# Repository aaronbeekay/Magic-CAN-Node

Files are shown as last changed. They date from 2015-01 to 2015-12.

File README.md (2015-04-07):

Magic-CAN-Node
==============

Magic CAN Node is a multifunctional, Controller Area Network (CAN)-enabled sensor interface module. It has the ability to connect, measure, and transmit data from a wide variety of sensors.

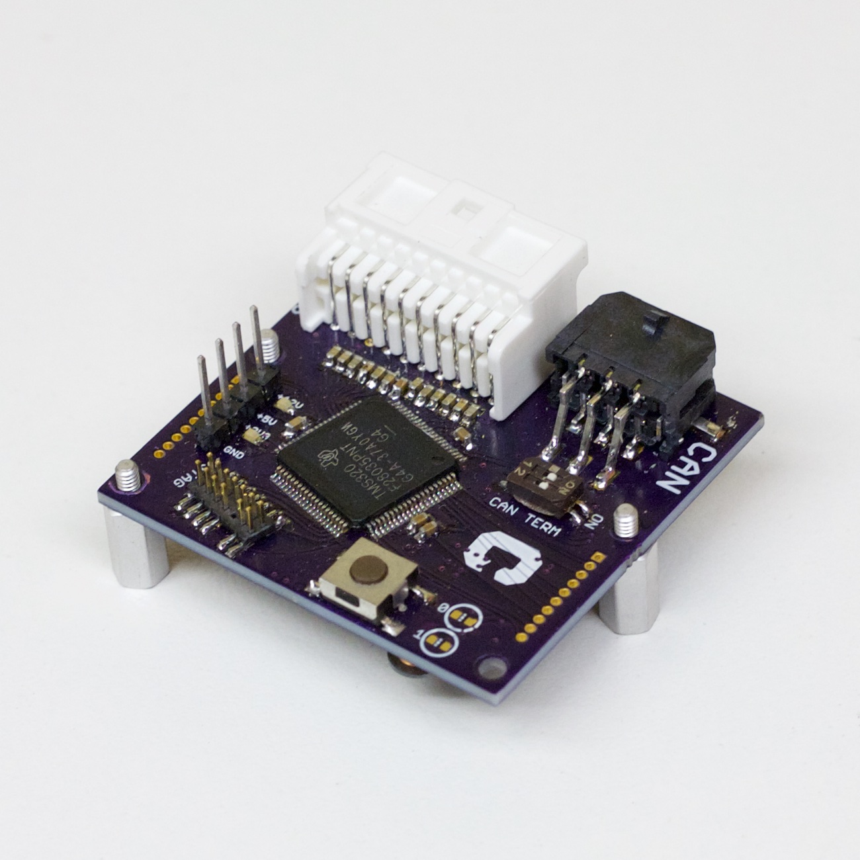
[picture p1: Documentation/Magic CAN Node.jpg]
Magic CAN Node


It's based on the Texas Instruments C2000 Piccolo, a 32-bit microcontroller with useful features. 

Some important features of the Magic CAN Node include:
* 12 analog inputs with buffering and anti-aliasing
* An onboard pushbutton and two general-purpose LEDs
* Access to SPI, I2C, and serial interfaces, as well as power and ADC pins, through standard "backpack" header
* Robust CAN interface, with onboard CAN termination
* Powered from +12V, with a wide 6-42V input range

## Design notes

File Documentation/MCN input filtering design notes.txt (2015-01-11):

Options for active filtering of analog inputs on MCN v2

1. Per-channel active filters
	- because of cost and board space concerns, anti-aliasing filter order is limited
	- seems practical to implement 2-order Butterworth (=24 op-amps, 6x TSSOP-16 packages)

2. External ADC
	- options:
		- TI ADS7953
			- 12-bit, 12- or 16-channel
			- has mux breakout for filtering
			- http://www.ti.com/lit/ds/symlink/ads7953-q1.pdf
		- TI ADS1158
			- 16-bit
			- 16-channel
			- http://www.ti.com/product/ads1158
			- SPI interface
		
3. External mux
	- two 12-channel muxes: still use the C2000 internal mux, but switch a "nice" signal conditioning filter inline into the channel of interest
	- options:
		- TI CD4067B
			- http://www.ti.com/product/cd4067b
			
FILTER DESIGN IDEAS
- cheater chip: http://www.ti.com/lit/ds/symlink/uaf42.pdf

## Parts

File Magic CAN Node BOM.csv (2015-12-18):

Qty | Description | Manufacturer | Mfg Name | Mfg part | Vendor | Vendor Part Num | Cost | Designator
12 | Capacitor, Ceramic, 33 nF, 50V, X7R, 10% | Passive | AVX | 06035C333KAT2A | NW | 66H6168 | 0.018 | C7, C8, C9, C10, C11, C12, C13, C15, C19, C20, C21, C28
1 | DIP switch, 0.05"""" pitch, 2pos, 50V | Switches | CTS Electrocomponents | 218-2LPST | DK | CT2182LPST-ND | 1.06 | SW3
2 | Header, female pin, 10x1pos, 1.27 mm pitch, select gold plated, through hole | Connectors | Multicomp | 2206SA-10-46 | NW | 11N6311 | 0.835 | X1, X2
1 | Micro-Fit header, 6pos, RA, SMD, with solder tabs | Connectors | Molex | 43045-0609 | DK | WM1827CT-ND | 3.2 | X3
1 | Micro-Clasp header, 20pos, 2 rows, RA, through-hole | Connectors | Molex | 55959-2030 | NW | 09J7572 | 1.13 | X5
1 | Schottky rectifier, 30V, 1A, SMA | Passives | Diodes Inc | B130-13-F | DK | B130-FDICT-ND | 0.43 | D1
4 | Inductor, Chip, 60ohm, 1.5A, 0603 | Passives | Taiyo Yuden | BKP1608HS600-T | DK | 587-1928-1-ND | 0.047 | L2, L3, L4, L5
4 | Capacitor, Ceramic, .1uF 25V 10% 0603 X7R | Passives | TDK | C1608X7R1E104K080AA | DK | 445-1316-1-ND | 0.011 | C22, C23, C24, C32
3 | Resistor, 169 ohm 125 mW, 1%, 100ppm, Thick Film 0805 | Passives | Vishay Dale | CRCW0805169RFKEA | NW | 52K9913 | 0.005 | R15, R36, R37
2 | Schottky diode, 30V, 800 mA, USC/SOT-323 | Passives | Toshiba | CUS08F30 | DK | CUS08F30H3FCT-ND | 0.34 | D8, D9
1 | Choke, common mode, 100 uH, 500 mA, 25% | Passives | Bourns Inc | DR331-104AE | NW | 29T3649 | 0.32 | L7
12 | Resistor, 100 kohm, 100mW, 1%, Thick Film, 0402 | Passives | Panasonic | ERJ-2RKF1003X | NW | 64R5249 | 0.014 | R20, R21, R22, R23, R24, R25, R26, R27, R28, R29, R30, R31
16 | Resistor, 1 kohm 100 mW, 1%, Thick Film, 0603 | Passives | Panasonic | ERJ-3EKF1001V | NW | 64R5308 | 0.012 | R1, R2, R3, R4, R5, R6, R7, R8, R9, R10, R11, R12, R13, R18, R32, R33
1 | Resistor, 5.6 kohm, 100 mW, 1%, 0603 | Passives | Panasonic | ERJ-3EKF5601V | NW | 64R5354 | 0.096 | R16
4 | Resistor, 60.4 ohm, 100 mW, 1%, 0603 | Passives | Panasonic | ERJ-3EKF60R4V | NW | 65T8495 | 0.096 | R17, R19, R34, R35
1 | Resistor, 1.5k ohm 125 mW, 5%, Thick Film, 200ppm, 0805 | Passives | Panasonic | ERJ-6GEYJ152V | NW | 65T8789 | 0.003 | R14
1 | Tactile switch, SPST-NO, 0.05A, 12V | Switches | TE Connectivity | FSM1LPATR | DK | 450-1760-1-ND | 0.33 | SW2
1 | 0.05"""" male pin header, 2 rows, 14 positions (TI JTAG) - surface mount, vertical | Connectors | Samtec | FTS-107-01-F-DV | NW | 56P3763 | 0.9 | X6
7 | Capacitor, Ceramic, 2.2UF, 10%, 25V, 0603, X5R | Passives | Murata | GRM188R61E225KA12D | NW | 13T1193 | 0.107 | C1, C2, C3, C4, C5, C6, C17
1 | Capacitor, Ceramic, 4.7 nF, 50V, X7R, 10%, 0603 | Passives | Murata | GRM188R71H472KA01D | NW | 38K1673 | 0.006 | C18
2 | Capacitor, Ceramic, 22 uF, 6.3V, X5R, 20%, 0805 | 22 uF | Murata | GRM21BR60J226ME39L | NW | 24R6338 | 0.091 | C30, C31
1 | Capacitor, Ceramic, 10UF, 35V, X5R, 10%, 1206 | Passives | Murata | GRM31CR6YA106KA12L | NW | 72R4211 | 0.355 | C16
1 | Capacitor, Ceramic, 1 uF, 50V, X7R, 10%, 1210 | Passives | Murata | GRM32RR71H105KA01L | NW | 97K0677 | 0.248 | C29
2 | LED, Green, 0603, 10mcd | LEDs | Osram | LGQ971 | NW | 05M0493 | 0.054 | LED2, LED3
1 | LED, Green, 0603, 10mcd | LEDs | Osram | LGQ971 | NW | 05M0493 | 0.054 | LED0
1 | IC, DC-DC Conv, Buck, 42 Vin, 1.25 MHz, SOT23-6 | ICs | Texas Instruments | LMR14206XMKE/NOPB | NW | 76T5004 | 2.72 | IC2
1 | IC, LDO VOLT REG, 3.3V, 0.5A, SOT-223-5 | ICs | Texas Instruments | LP38693MP-3.3/NOPB | NW | 41K7496 | 1.53 | IC3
1 | Female pin header, 2x3 pos, 2mm pitch, selective gold plated | Connectors | Harwin | M22-7140342 | DK | 952-1357-5-ND | 1.15 | X4
1 | Capacitor, Ceramic, 4.7 uF 25V, 10%, X5R, 0805 | Passives | Multicomp | MC0805X475K250CT | NW | 06R4181 | 0.037 | C14
3 | ZENER DIODE, 200mW, 3.3V, SOD-323 | Passives | ON Semiconductor | MM3Z3V3ST1G | NW | 09R9503 | 0.15 | D5, D6, D7
2 | Resistor, Thick Film, 20 kohm, 100 mW, 1%, 0603 | Passives | Vishay Dale | RC0603FR-0720KL | NW | 68R0068 | 0.017 | R43, R44
1 | Resistor, 36 kohm, 1%, 100 mW, 0603 | Passives | Yageo | RC0603FR-0736KL | DK | 311-36.0KHRCT-ND | 0.0108 | R47
1 | Resistor, 10k ohm 100 mW, 5%, 100ppm, 0603 | Passives | Yageo | RC0603JR-1010KL | NW | 68R0215 | 0.008 | R46
1 | Inductor, 18 uH, 1.5 A, unshielded, 15%, 8012 | Passives | Bourns | SDR0604-180YL | DK | SDR0604-180YLCT-ND | 0.47 | L6
2 | TVS DIODE 30VWM 48.4VC SMB | Passives | Littelfuse | SMBJ30CA | DK | SMBJ30CALFCT-ND | 0.423 | D3, D4
1 | LED, Yellow, 0603, 14mcd | LEDs | Lumex | SML-LX0603YW-TR | NW | 75K1443 | 0.152 | LED1
1 | IC, CAN TX/RX, 1 MBps, 5.5V, 8-SOIC | ICs | Texas Instruments | SN65HVD1050D | NW | 70K4439 | 1.32 | IC8
1 | IC, Buffer, 2-bit, non-invert, open drain, SOT-23-6 | ICs | Texas Instruments | SN74LVC2G07DBVR | DK | 296-13494-1-ND | 0.59 | IC5
1 | Diode, Schottky, 40V, 500 mA, SOD-123 | Passives | STMICROELECTRONICS | STPS0560Z | NW | 89K1573 | 0.762 | D2
3 | IC, Quad Op-Amp, Single Supply Rail-Rail, 500 KHz, TSSOP-14 | ICs | Texas Instruments | TLV2764IPWR | NW | 76C8534 | 3.06 | IC4, IC6, IC7
1 | IC, MCU, C2000 piccolo, LQFP80 | ICs | Texas Instruments | TMS320F28035PNT | DK | 296-32764-ND | 12.38 | IC1

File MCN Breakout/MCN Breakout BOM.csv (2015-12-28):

Qty | Description | Category | Manufacturer | Mfg part | Vendor | Vendor Part | Cost | Part References
1 | Header, Male pin, .1", 1-row, 20 pos, breakable (Short Pins) | Connectors | FCI | 68000-236HLF | DK | 609-3465-ND | 1.44 | SV2, SV3
1 | Micro-Fit header, 6pos, RA, SMD, with solder tabs | Connectors | Molex | 43045-0609 | DK | WM1827CT-ND | 3.2 | X7
1 | MicroClasp plug, 20pos, dual row | Connectors | Molex | 51353-2000 | DK | WM3363-ND | 0.73 | X1
1 | 0.1" Male Header - 2 rows, 14 positions (TI JTAG) - Through Hole, Vertical | Connectors | FCI | 67996-114HLF | DK | 609-3491-ND | 0.75 | SV1
1 | BNC jack, 50 ohm, PCB mount, right-angle | Connectors | Molex | 73171-4230 | DK | WM5281-ND | 1.61 | X6
1 | DE-9 (DB-9) receptacle, 9 positions, PCB mount, right-angle | Connectors | TE Connectivity | 1734354-1 | DK | A35107-ND | 1.43 | X8
1 | Male pin header, 2x3pos, 2mm pitch, selective gold plated | Connectors | Harwin | M22-2520305 | DK | 952-1318-ND | 0.43 | X2
2 | Female pin header, 10 pos, 2mm pitch, selective gold plated | Connectors | Harwin | M22-7131042 | DK | 952-1354-5-ND | 1.49 | X10, X11
1 | Binding post, insulated, red, 6-32 stud size | Connectors | Cinch Connectivity | 111-0702-001 | DK | J10125-ND | 4.05 | X5
1 | Binding post, insulated, black, 6-32 stud size | Connectors | Cinch Connectivity | 111-0703-001 | DK | J10126-ND | 4.05 | X4

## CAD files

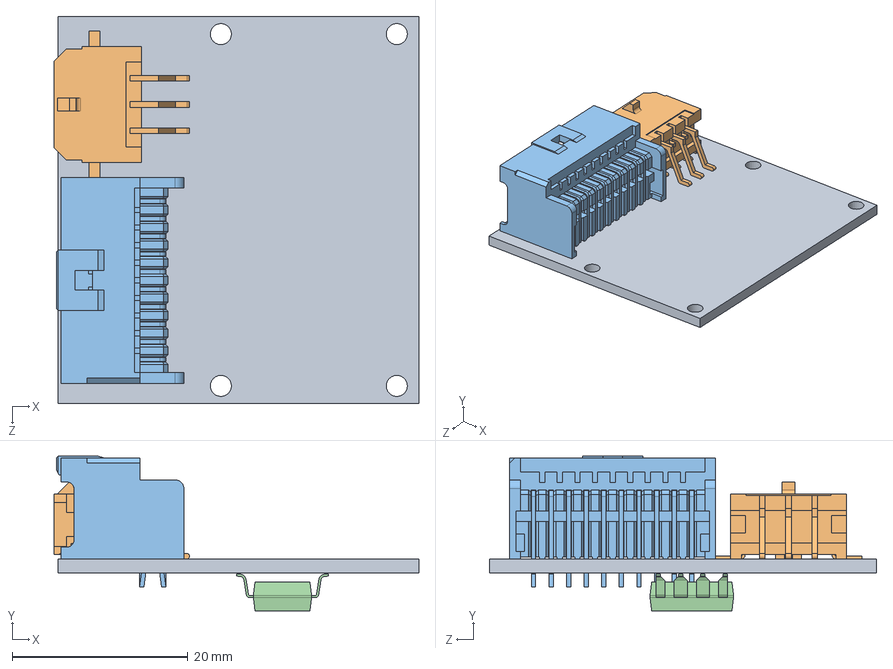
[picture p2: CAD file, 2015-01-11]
MCAD/Magic CAN Node.SLDASM
41.5 x 17.6 x 44.0 mm
Magic CAN Node PCB
Molex MicroFit 6pos RA header - solder tabs - 43045-0609
Micro-Clasp 20ckt dual-row header - 55959-2030
8-DUB__R-PDSO-8

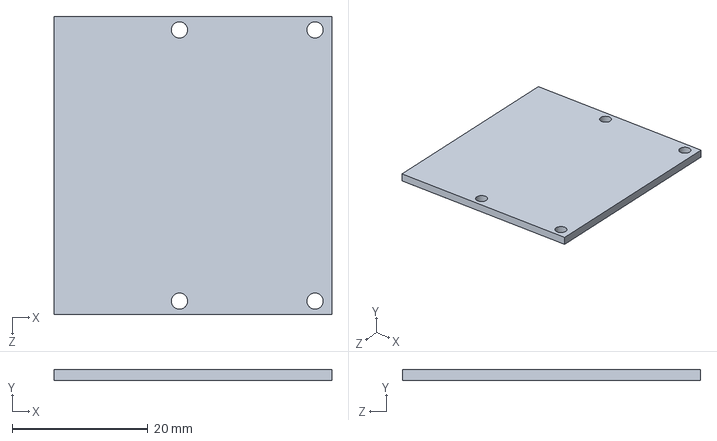
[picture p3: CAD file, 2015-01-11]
MCAD/Magic CAN Node PCB.SLDPRT
41.0 x 1.60 x 44.0 mm

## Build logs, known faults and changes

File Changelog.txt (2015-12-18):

Magic CAN Node - changelog

# v1.0.0 (r01)
(initial draft)

# v1.0.1 (r02) - 2014-02-10
- Fix incorrect drill size for X4.
- Add mating connectors and terminals as BOM entries in schematic (instead of manually adding later).
- Invert 12V switching to avoid glitch on processor startup
- Update TI component packages (IC5, IC6) to DBV package to match stocked components
- FIXME: Replace unsourceable ESD protection arrays IC7, IC2

VERSION NUMBERING UPDATE - November 2014
r02 is now v1.0.1.

# v.2.0 - 2014-12-04
- Redesign analog sensor input filter circuit to reflect new sensor measurement strategy:
	* Analog filter on each channel is an RC anti-aliasing filter with f_3dB = 5 kHz
	* Add option for differential-mode analog inputs (AINx to AIN-)
- Change 12V-3V3 power supply: use circuit from Battery Interface Module r02 (v.1.0.1) because TPS560200-based circuit from Magic CAN Node v.1.0.1 was unsourceable
- Remove ESD protection diode arrays
- Remove switched +12V output and associated circuit
- Change CAN connectors: remove AMPSEAL CAN connectors, replace with Micro-Fit 6pin
- Change JTAG header to 0.05" pitch
- Remove 'CAN_RESET' button
- Add '+3V3 OK' and '+12V OK' indicator LEDs

# v2.1 - 2015-03-23
- Replace CAN transceiver (ISO1050) with replacement (SN65HVD1050), for standardization
- Add 100k pulldowns to analog inputs.
- Tie VREFHI to +3V3 to enable ratiometric analog measurements.

# v2.2 - 2015-12-xx
- Add GPIO input filter circuit to general-purpose inputs.
- Add blind-mate input header, X4, to enable usage as daughtercard (no wire-to-board connections).
- Change CAN transceiver level-shifting diode, D5, from 3V to 3.3V to reduce unique part count.
- Fix LED resistor values and change components accordingly.

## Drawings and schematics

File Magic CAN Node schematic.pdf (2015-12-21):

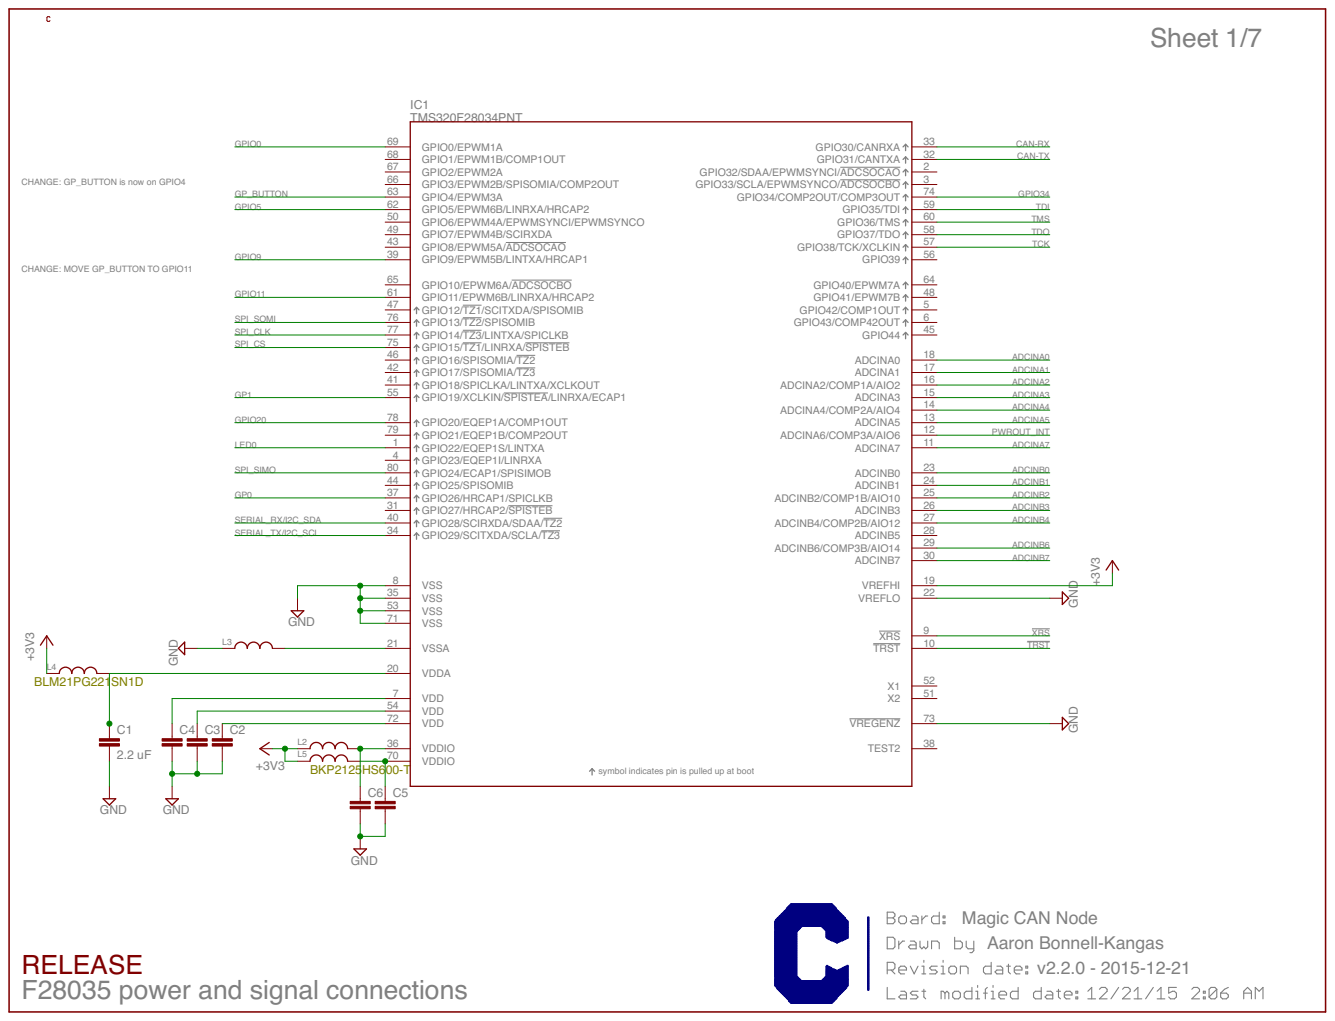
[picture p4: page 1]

CAN-RX CAN-TX

CHANGE: GP_BUTTON is now on GPIO4

35
53 | | 9 TRST XRS 10 TRST 52

symbol indicates pin is pulled up at boot

RELEASE
F28035 power and signal connections

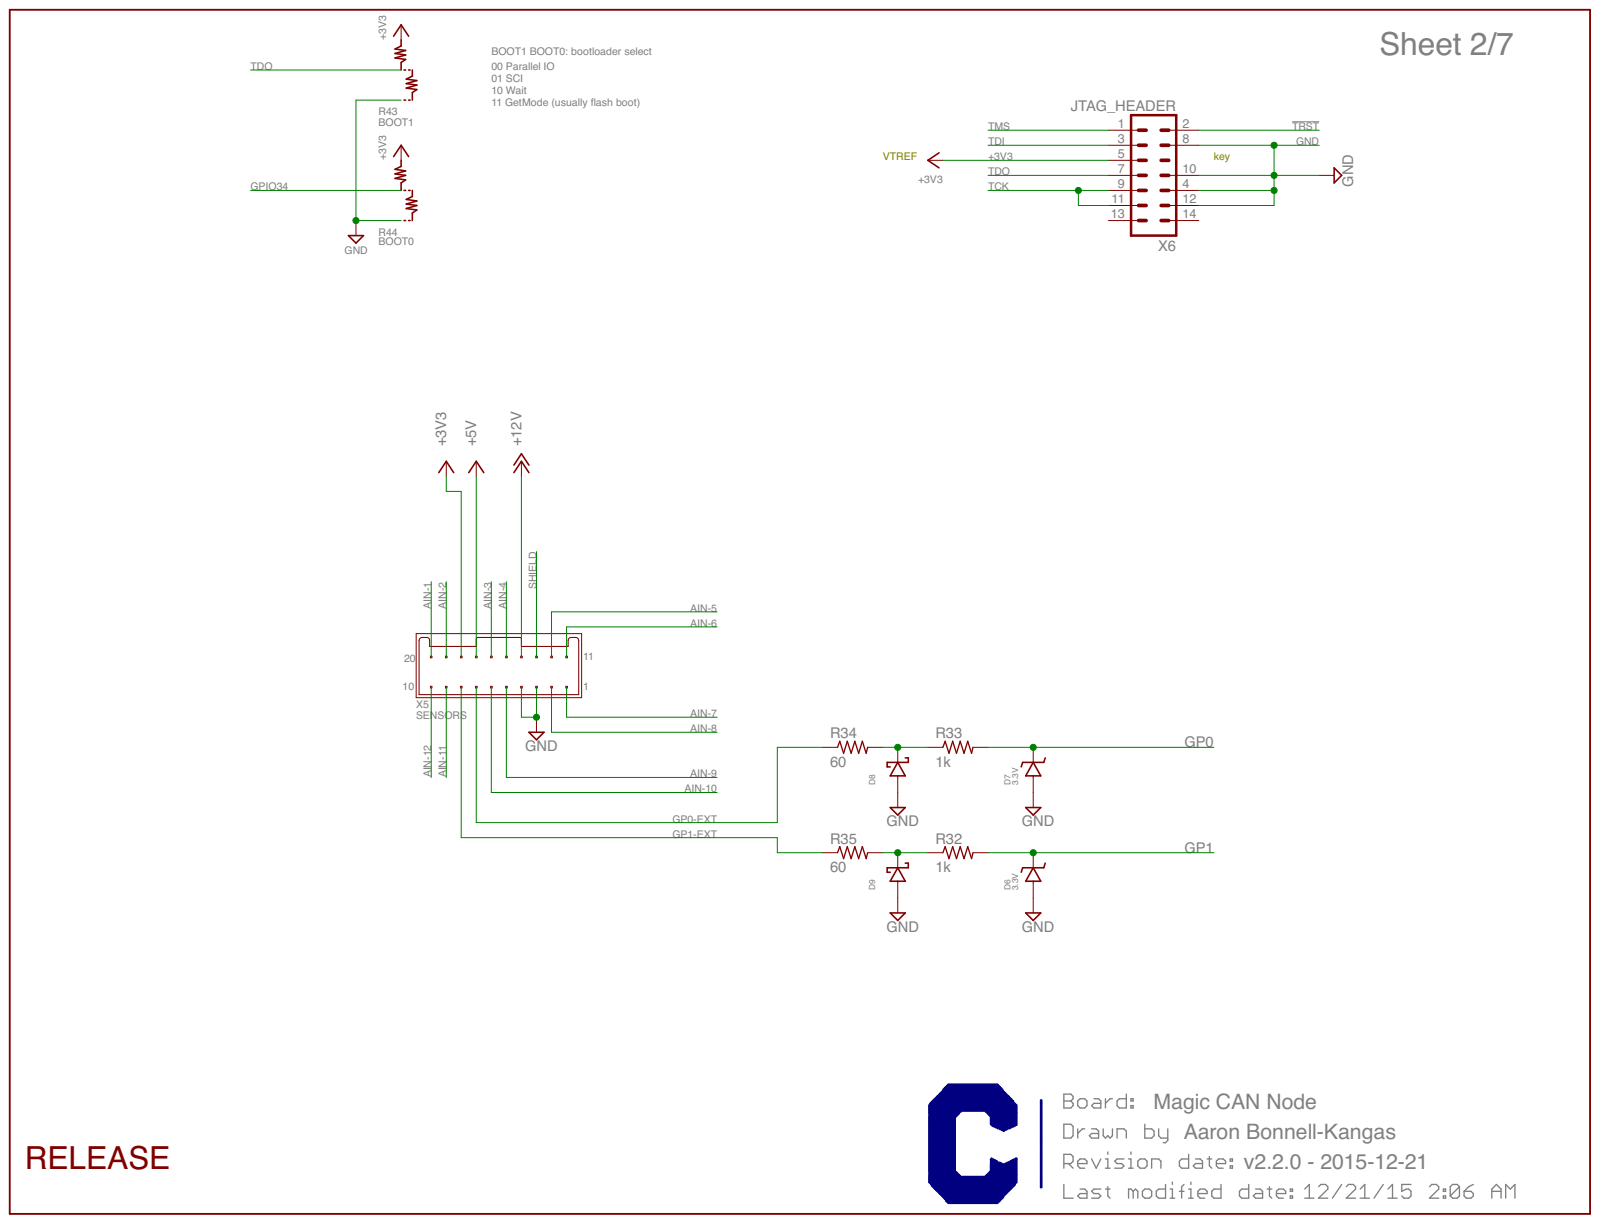
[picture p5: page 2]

BOOT1 BOOT0: bootloader select 00 Parallel IO

01 SCI 10 Wait 11 GetMode (usually flash boot)

AIN-1 AIN-2 AIN-3 AIN-4SHIELD

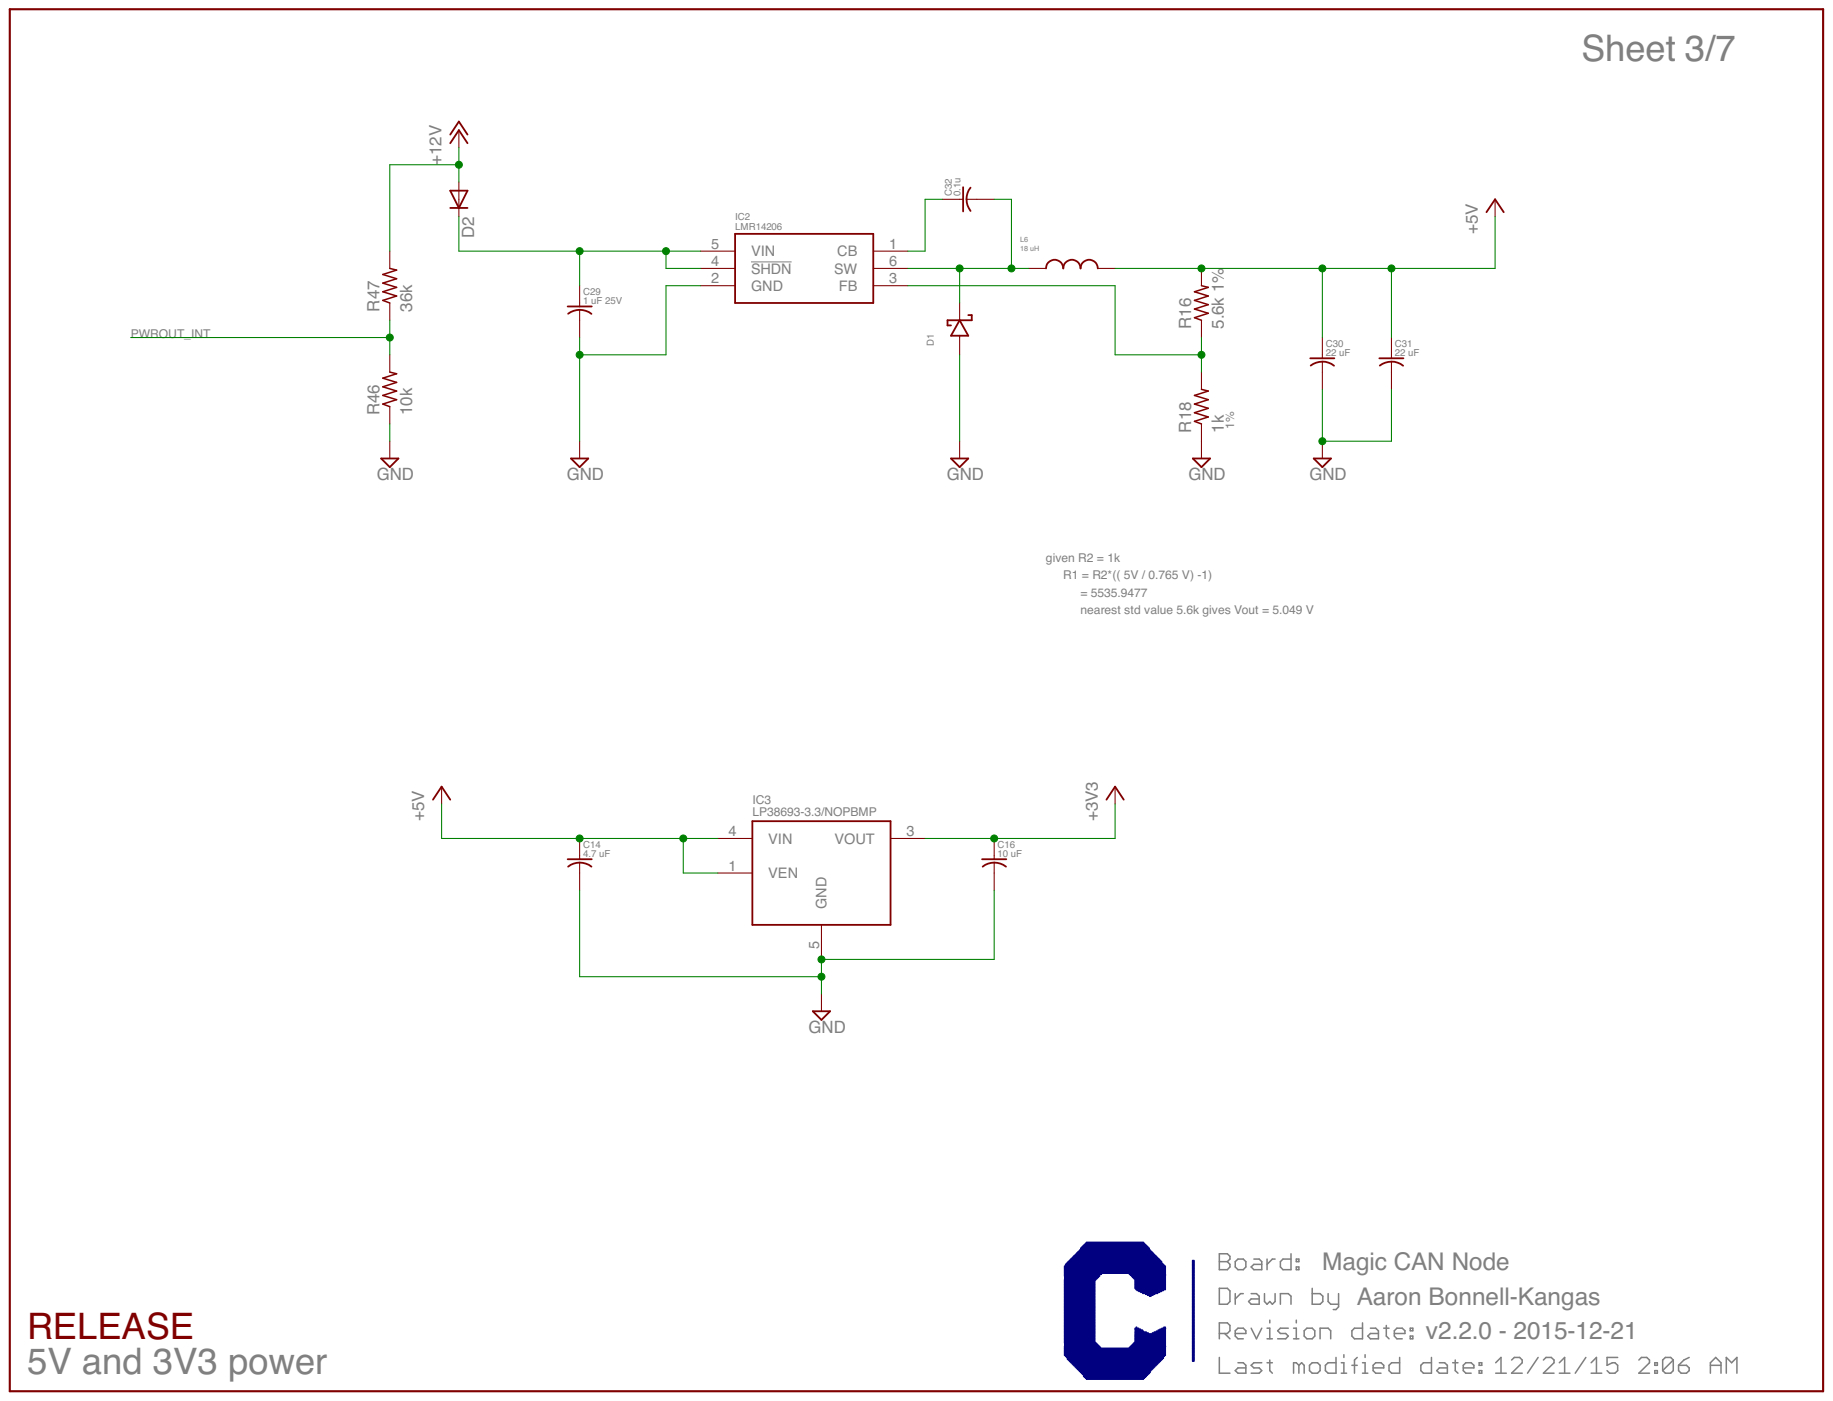
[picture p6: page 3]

nearest std value 5.6k gives Vout = 5.049 V

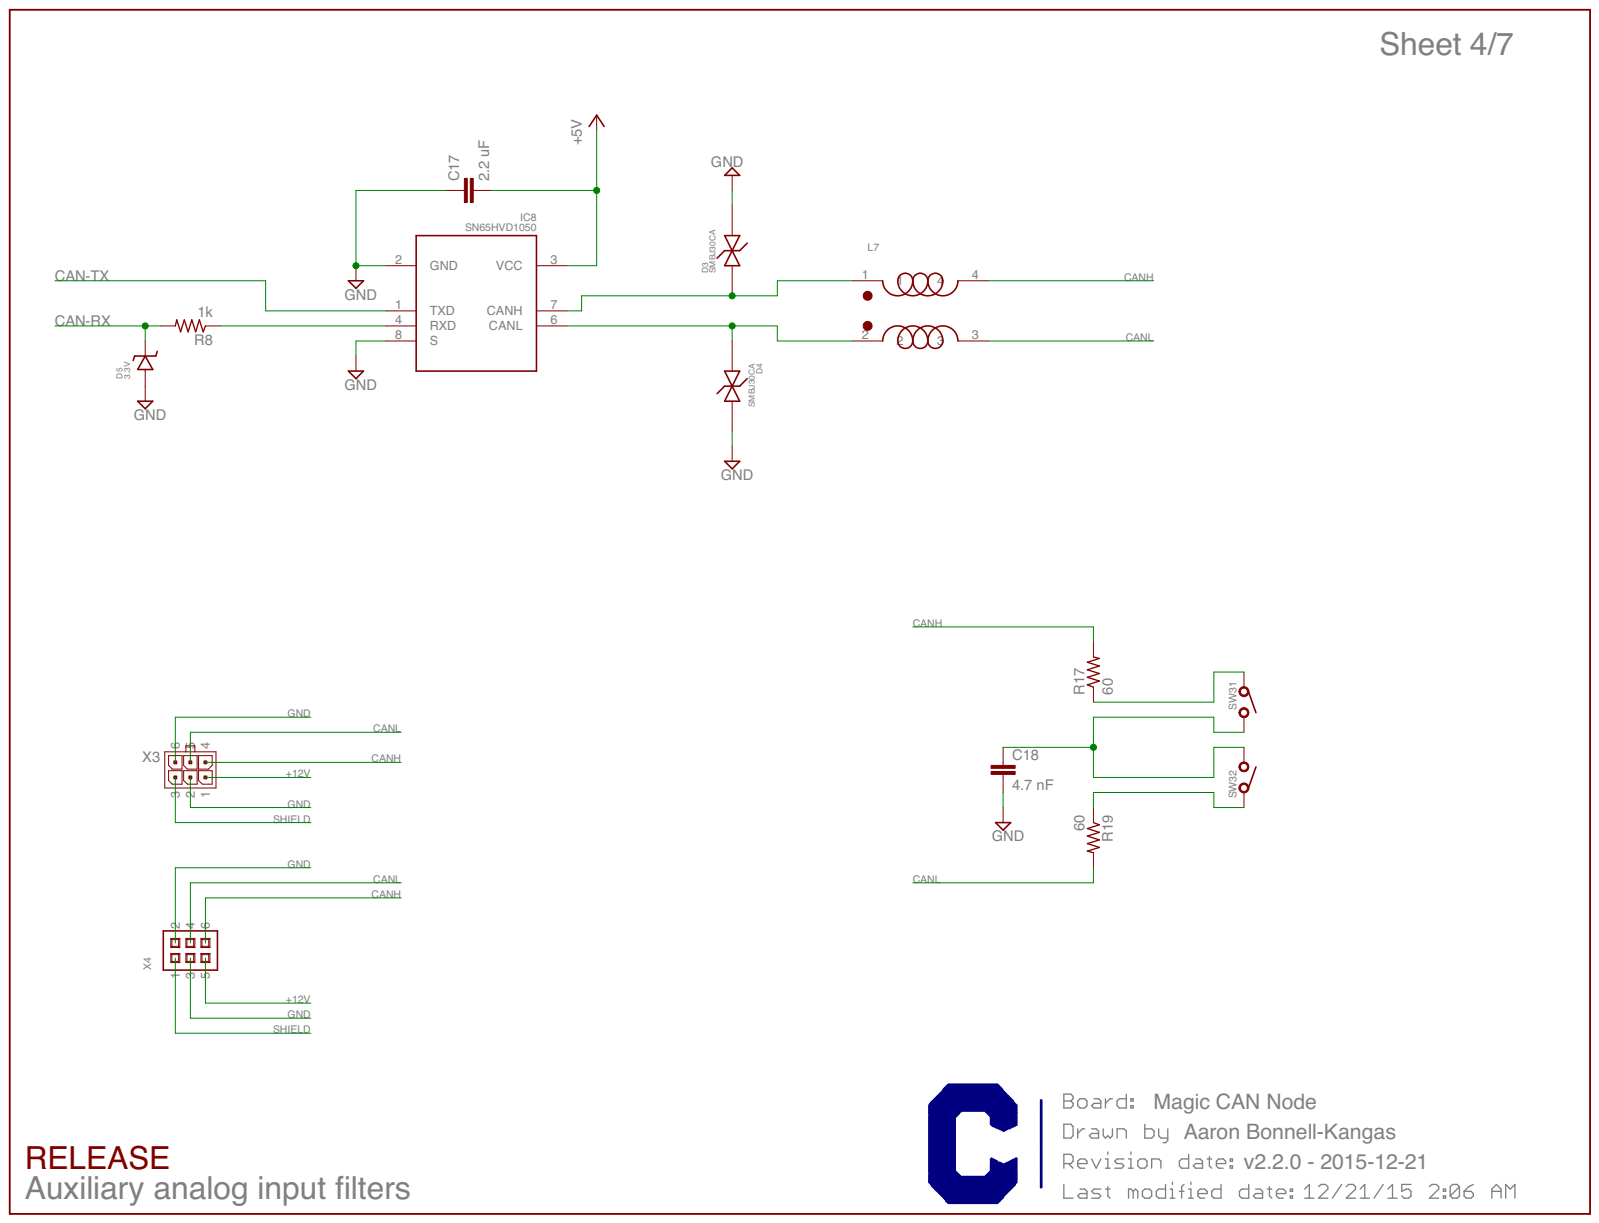
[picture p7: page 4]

RELEASE
Auxiliary analog input filters

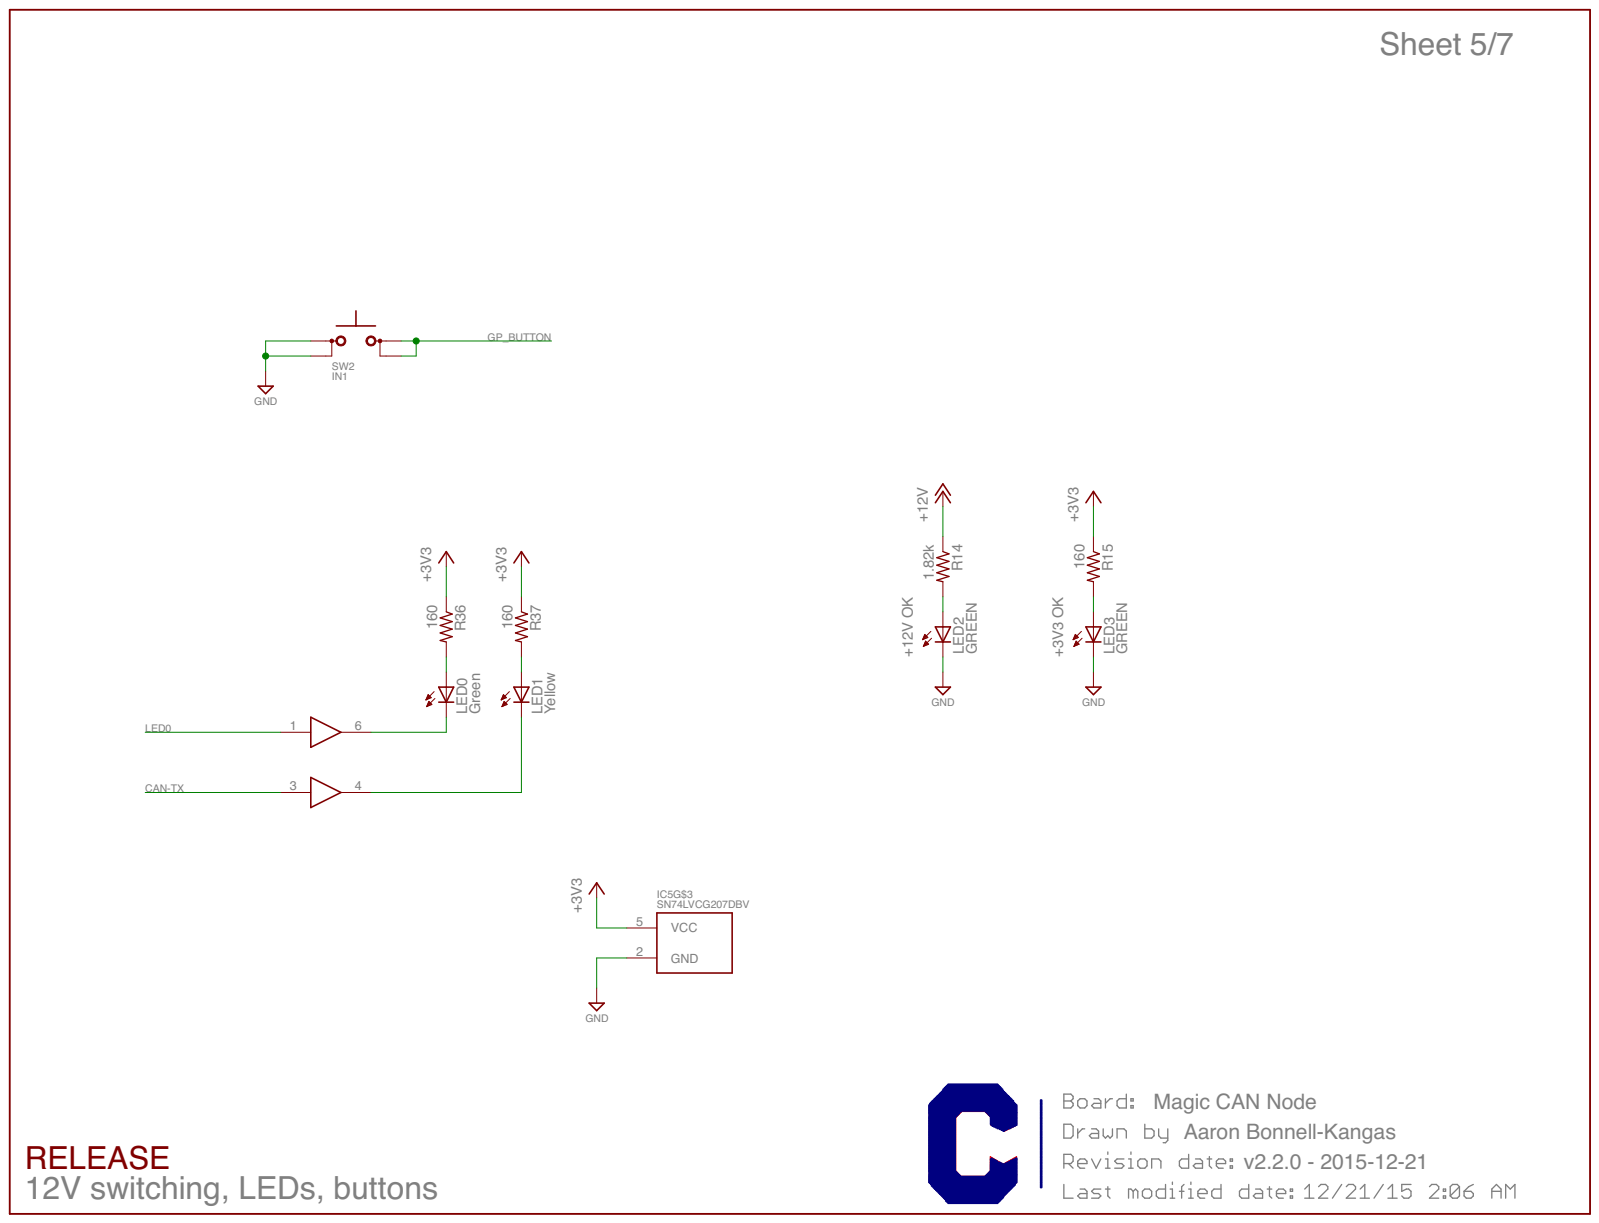
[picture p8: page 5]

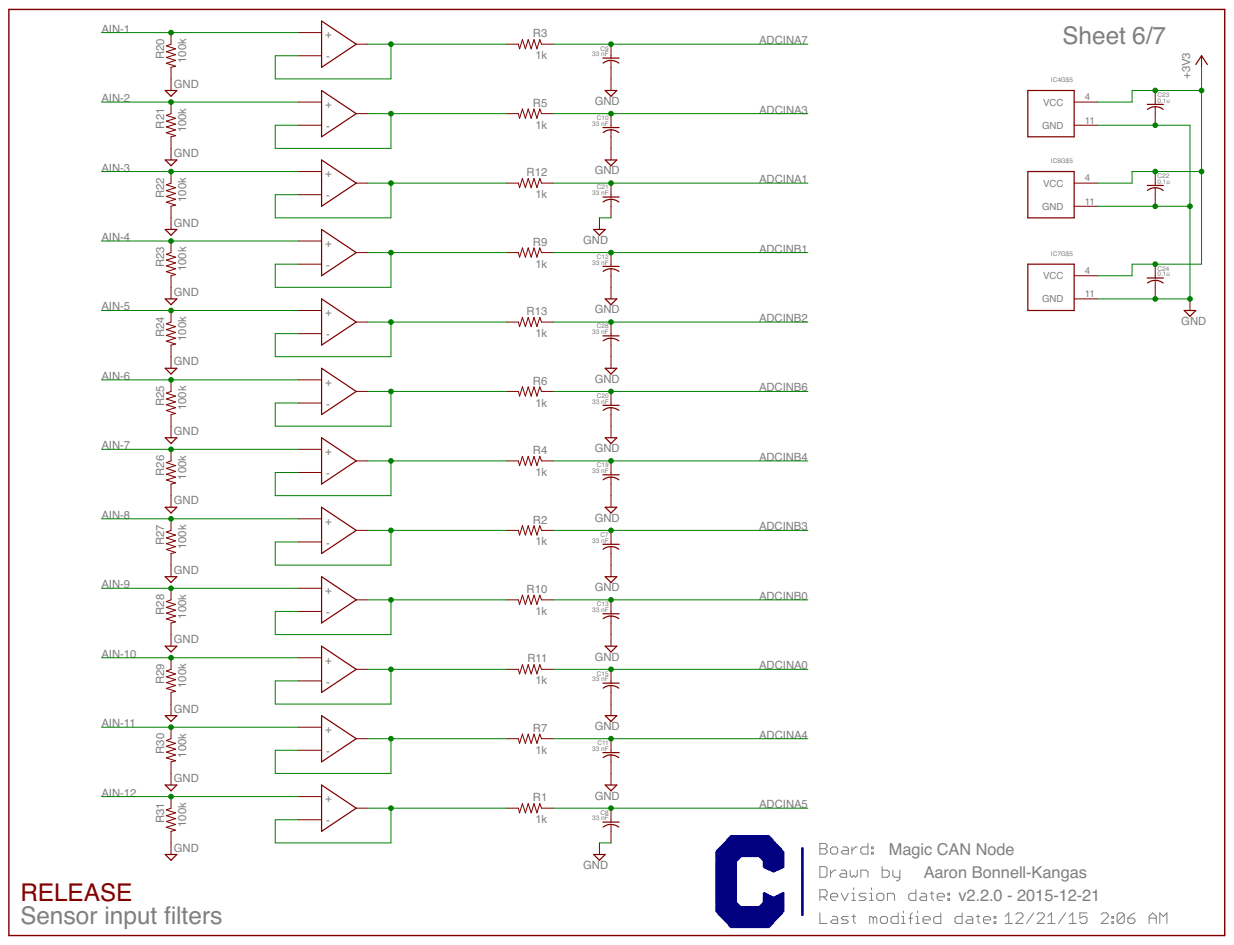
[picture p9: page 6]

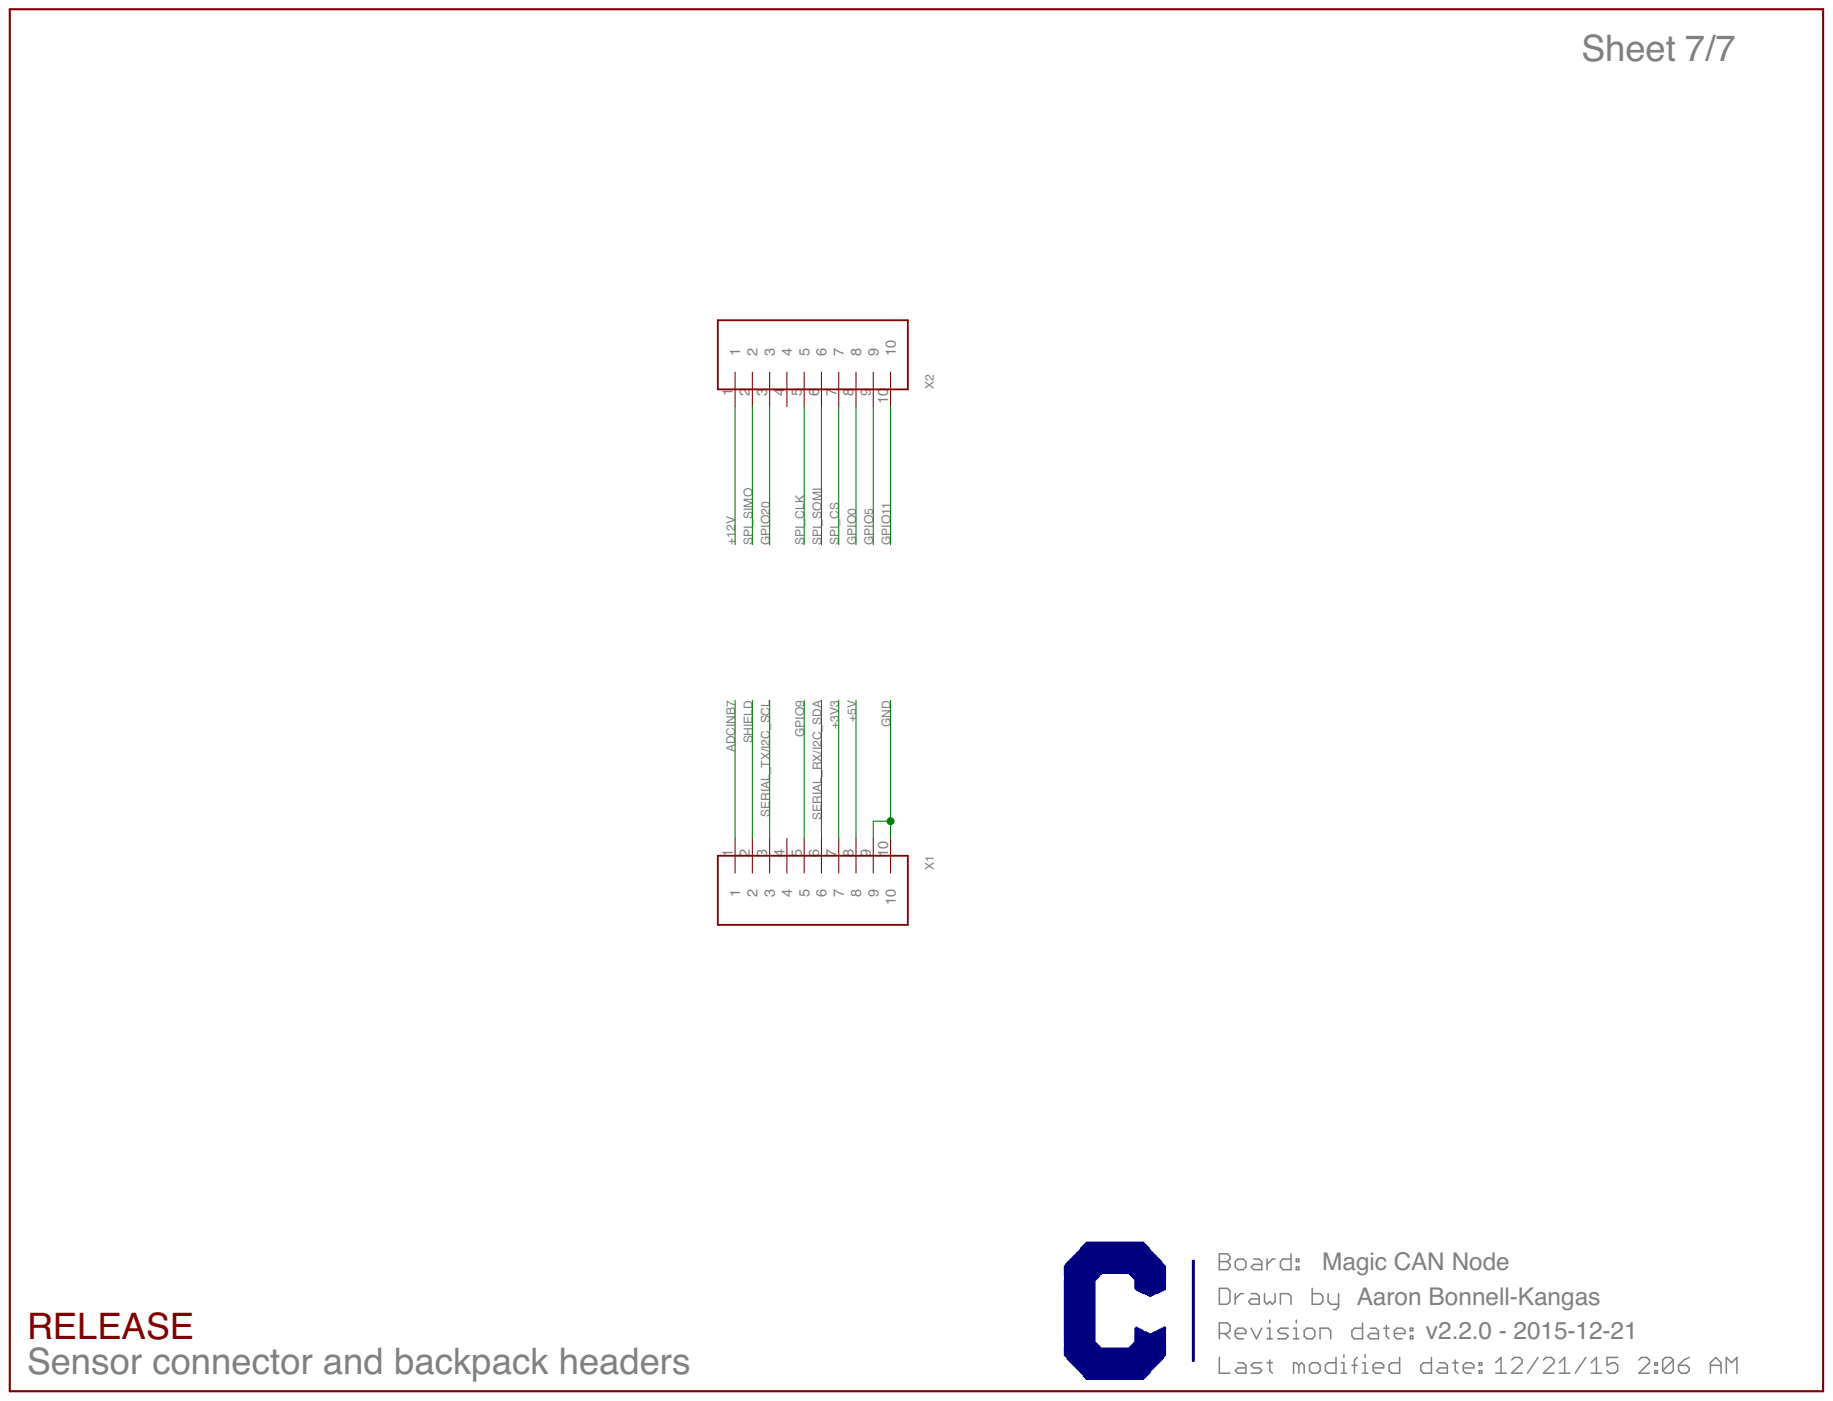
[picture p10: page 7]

RELEASE
Sensor connector and backpack headers

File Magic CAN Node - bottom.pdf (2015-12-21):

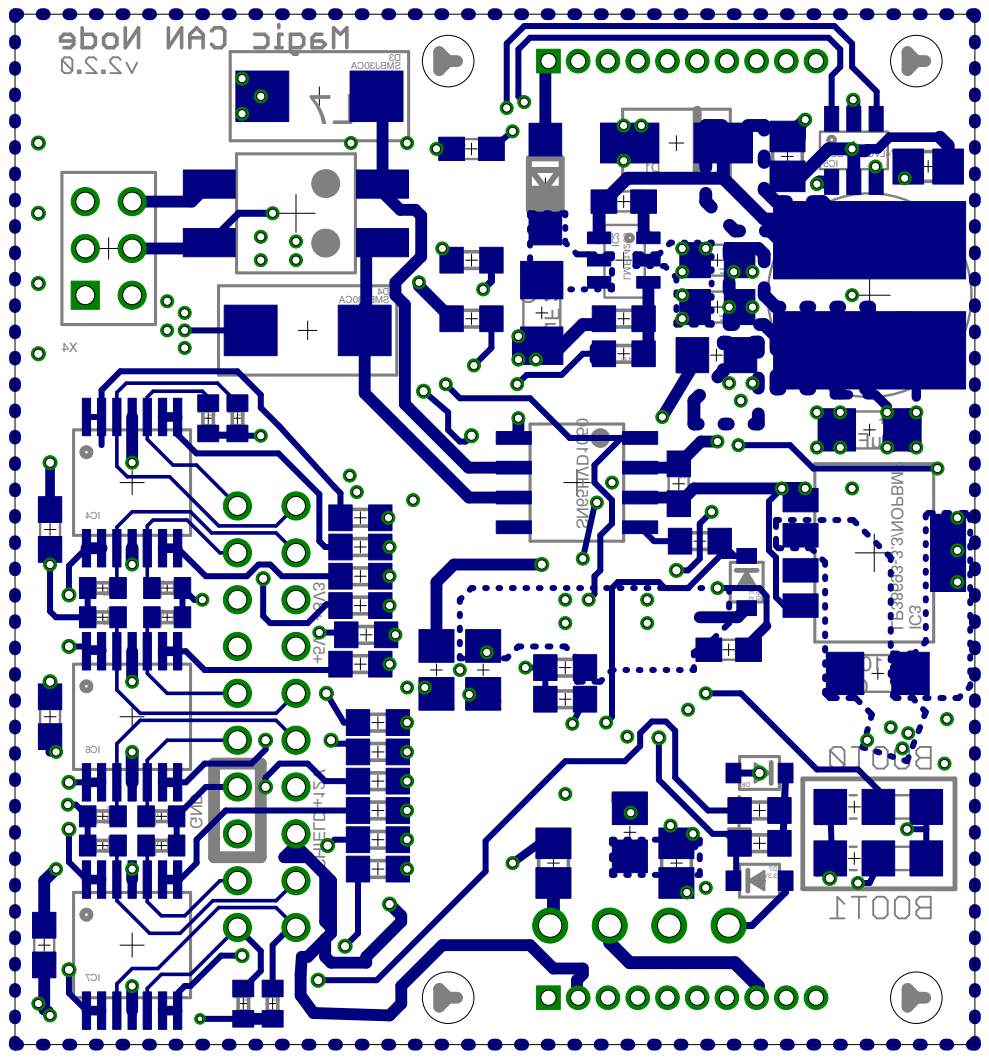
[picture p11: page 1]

Fu 2. 2 VBD702 GCVL47 NS 160061 k01 k63 k1k1k1k1 k1k1 k1k1k1 1.82k 160 LMR14206 1 uF 25V Fu 22 Fu 22 %1 k6. 5 k1 18 uH u1. 0 LP38693-3.3/NOPBMP Fu 7. 4 Fu 01 2.2 uF AC03J B MS AC03J B MS 0606 Fn 7. 4 k1k1k1 0.1u 0.1u 0.1u SN65HVD1050 3.3V k1 100k k001 k001 k001 k001 100k 100k k001 k001 k001 k001 100k V3. 3 k1 06 3 C 5 CI R36 73 R L2 L3L4 5L 34 R 44 R D2 64 R 74 R 1 R3 R5 R7 R 9 R 01 R 11 R21 R31 R R14 R15 IC2 C29 03 C 13 C 61 R 81 R L6 1 D 23 C IC3 41 C 61 C 4 CI 6 CI 7 CI C17 3 D 4 D 7L 71 R 91 R 81 C 2 R4 R6 R C22 C23 C24 D5 8 R R20 12 R 22 R 32 R 42 R R25 R26 72 R 82 R92 R 03 R R31 4X 7 D33 R 43 R8 D +12V GND +3V3 SHIELD +5V

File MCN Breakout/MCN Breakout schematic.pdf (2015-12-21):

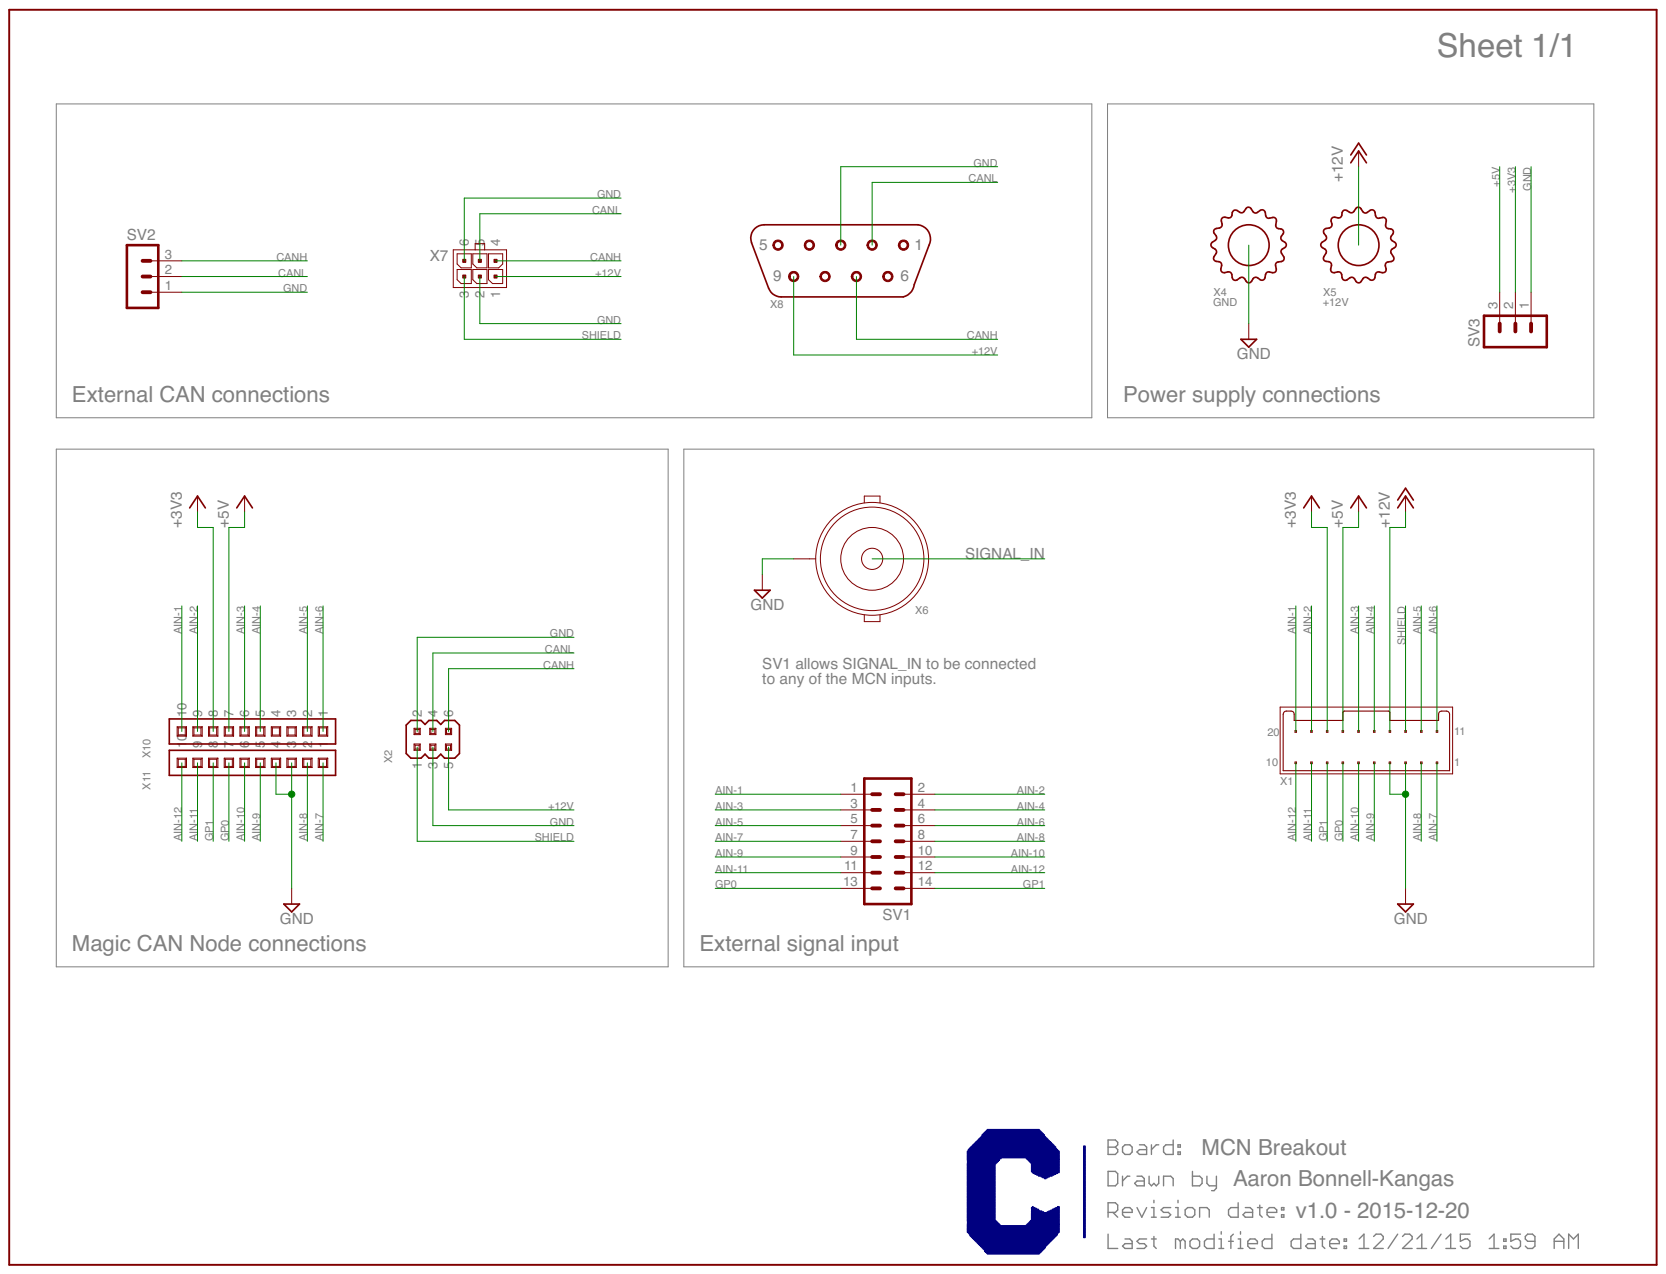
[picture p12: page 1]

SV1 allows SIGNAL_IN to be connected
to any of the MCN inputs.

Magic CAN Node connections

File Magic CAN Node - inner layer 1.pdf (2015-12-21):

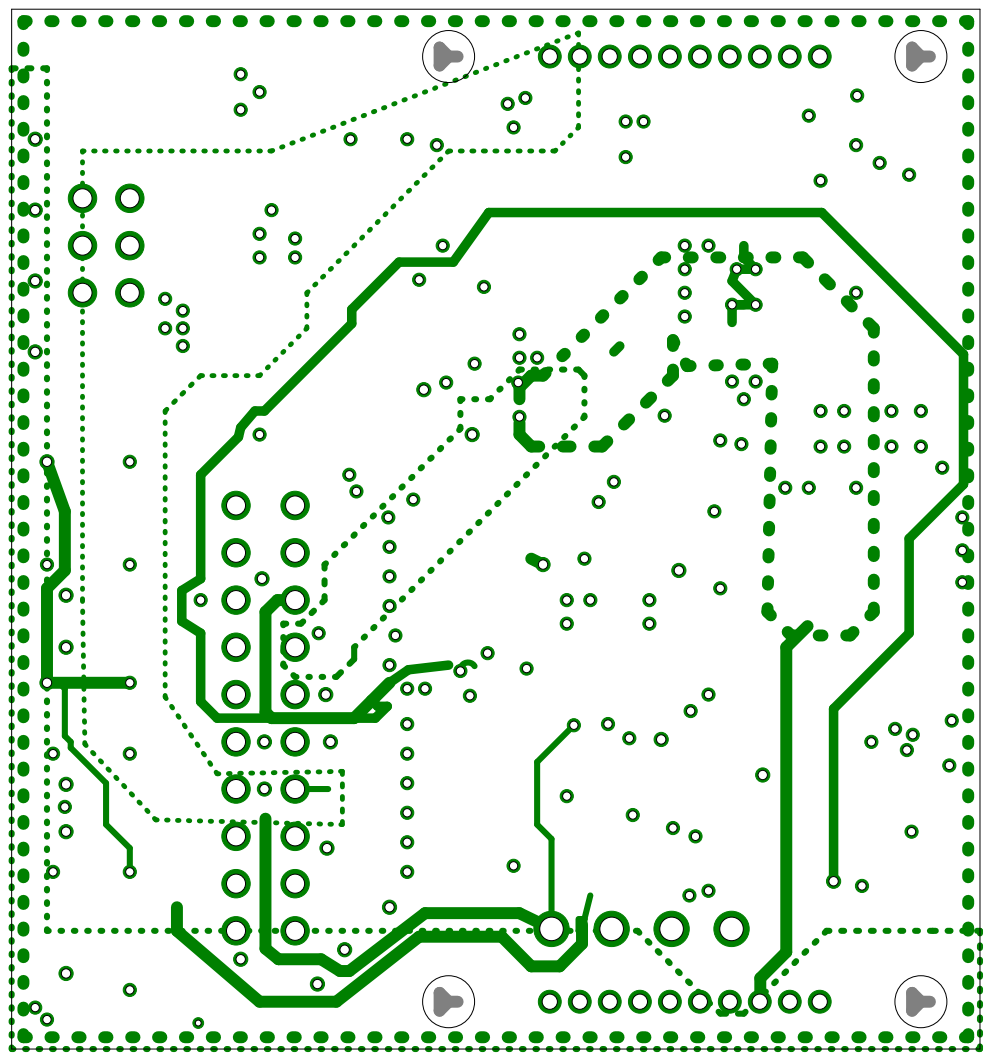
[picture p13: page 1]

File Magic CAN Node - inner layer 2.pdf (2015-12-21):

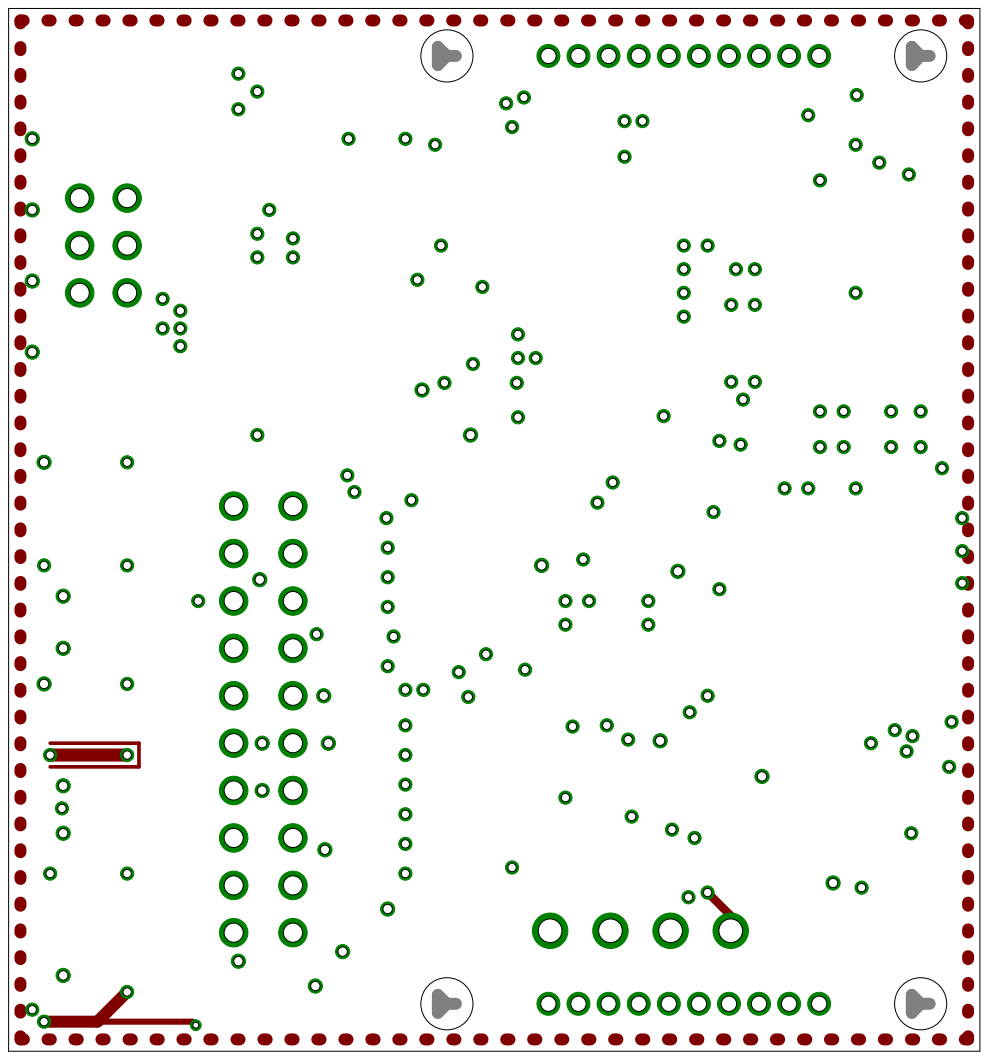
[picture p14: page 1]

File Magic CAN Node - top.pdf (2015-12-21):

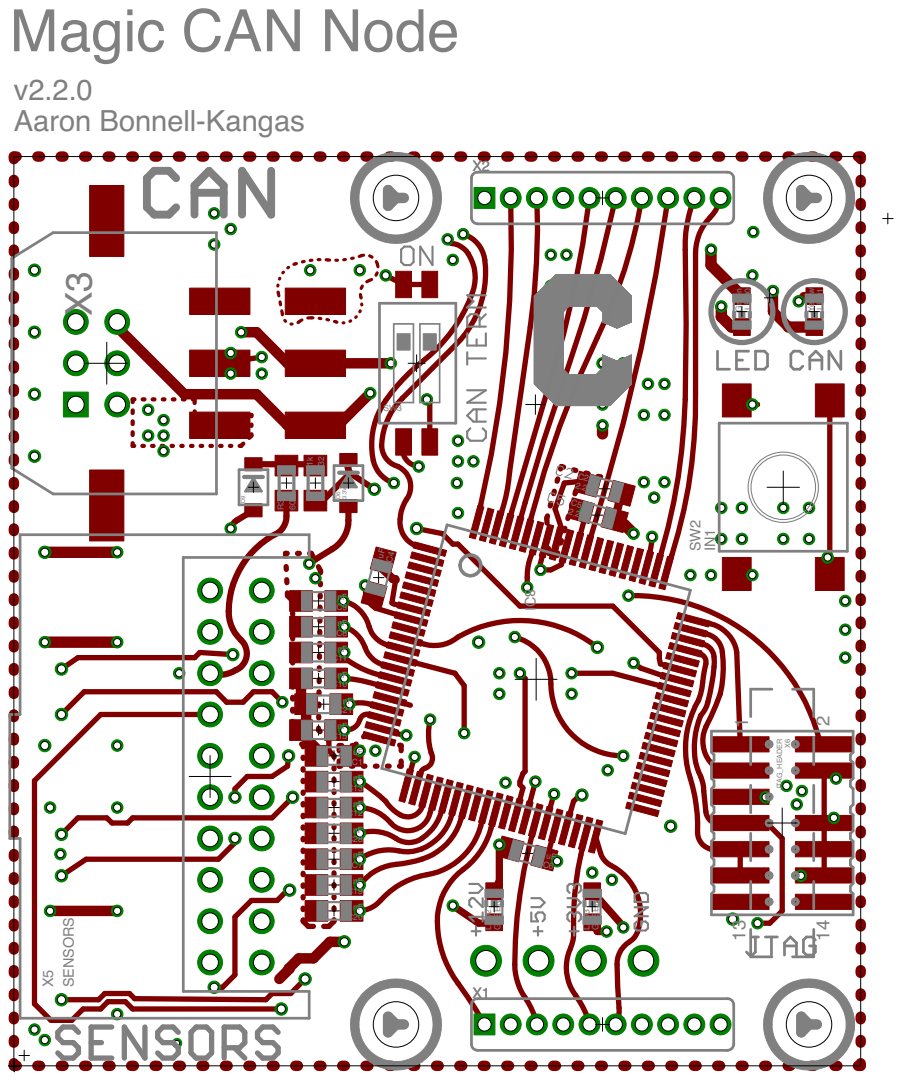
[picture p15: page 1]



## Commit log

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2014-10-27 Draft layout of MCN v2.0 - physical size only
    [Magic CAN Node.brd, Magic CAN Node.sch]
2014-11-11 Add draft of input filter circuit, wire CAN connectors
    [Magic CAN Node.brd, Magic CAN Node.sch]
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2014-11-12 remove M12-5 "external" CAN connector (in favor of "CAN backplane")
    [Magic CAN Node.brd, Magic CAN Node.sch]
2014-11-12 Replace 12V-3V3 power supply with LMR14206-based design from BIM v1.0.1
    [Magic CAN Node.brd, Magic CAN Node.sch]
2014-11-12 draft layout of PCB w/ dimensions
    [Magic CAN Node.brd, Magic CAN Node.sch]
2014-11-16 draft version with ADS7952 ADC; include notes on ADC and input filter selection
    [Magic CAN Node.brd, Magic CAN Node.sch]
2014-11-17 V2 CAN circuitry schematic done. Pull the Library changes to your computer so you have the new parts on your local Comp.
    [Magic CAN Node_Anil.sch]
2014-11-17 Added circuitry for +3V3 LDO. On the same sheet as CAN circuitry since sheets are not available for free version of Eagle.
    [Magic CAN Node_Anil.sch]
2014-11-19 <unfortunately I forget what I did here>
    [Magic CAN Node.brd, Magic CAN Node.sch]
2014-11-19 Previous commit was an error - this is current working state
    [Magic CAN Node.brd, Magic CAN Node.sch]
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2014-11-19 modify 12V SMPS to give 5V out (change R16, R18)
    [Magic CAN Node.brd, Magic CAN Node.sch]
2014-11-19 Add 5V - 3V3 circuit from Magic CAN Node_Anil.sch. Correct V_en connection (move from +3V3 to +5V).
    [Magic CAN Node.brd, Magic CAN Node.sch]
2014-11-20 Add CAN transceiver, input protection, and termination from @aeozyalcin. Add input buffers.
    [Magic CAN Node.brd, Magic CAN Node.sch]
2014-11-21 Ugh. Lost another few hours of work. This is somewhere in the last six hours of progress on the board.
    [Magic CAN Node.brd, Magic CAN Node.sch]
2014-11-21 Fix board/schematic consistency errors from data loss
    [Magic CAN Node.brd, Magic CAN Node.sch]
2014-11-21 rework SENSORS pinout; assign pins on buffer amps
    [Magic CAN Node.brd, Magic CAN Node.sch]
2014-11-21 route op-amp input traces
    [Magic CAN Node.brd, Magic CAN Node.sch]
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2014-11-21 create AIN -> ADC assignments
    [Magic CAN Node.brd, Magic CAN Node.sch]
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2014-11-26 Revised pinout for SENSORS connector (this should be final)
    [Magic CAN Node.brd, Magic CAN Node.sch]
2014-11-26 Begin backpack connector pinout. Continued board layout work.
    [Magic CAN Node.brd, Magic CAN Node.sch]
2014-11-27 Continue PCB layout; create ground and power planes
    [Magic CAN Node.brd, Magic CAN Node.sch]
2014-11-29 route so hard i must be a grad student
    [Magic CAN Node.brd, Magic CAN Node.sch]
2014-11-29 Changed a bunch of the breakout traces to pointless showoffy curved traces for no good reason
    [Magic CAN Node.brd]
2014-11-29 I hope nobody ever reads these
    [Magic CAN Node.brd]
2014-11-29 Create .sldasm file for mech to work from
    [43045-0609.SLDPRT, 55959-2030.SLDPRT, ISO-1050.SLDPRT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]
2014-12-01 Rearrange AIN pins to be more readable. Generate draft PDF of schematic.
    [Magic CAN Node.brd, Magic CAN Node.sch]
2014-12-01 Update CAN connector package. Finish board routing. Add some silkscreen labels.
    [Magic CAN Node.brd, Magic CAN Node.sch]
2014-12-01 Route forgotten GPIO pins on SENSORS connector. Fix a couple of DRC errors. Lay down SHIELD polygons.
    [Magic CAN Node.brd, Magic CAN Node.sch]
2014-12-01 A few more final cleanup tasks. Update schematic as v2-beta.
    [Magic CAN Node.brd, Magic CAN Node.sch]
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2014-12-03 Fix routing issues on SHIELD ground plane. Connect VREFLO to GND.
    [Magic CAN Node.brd, Magic CAN Node.sch]
2014-12-04 Fix erroneous "VDD" airwires. This version passes OSH Park 5-5 DRC.
    [Magic CAN Node.brd, Magic CAN Node.sch]
2014-12-04 Add C logo to top silk.
    [Magic CAN Node.brd, Magic CAN Node.sch]
2014-12-04 Add "CAN TERM" label to termination switch. Update Current C.
    [Magic CAN Node.brd, Magic CAN Node.sch]
2014-12-04 Update schematic and board PDFs. Clean up directory. Add Gerbers (OSH Park 4-layer).
    [Magic CAN Node r02 BOM.csv, Magic CAN Node.brd, Magic CAN Node_Anil.sch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]
2014-12-09 Change C14 and C16 (+3V3 LDO filter capacitors) to 4.7u and 10u as recommended in upstream design
    [Magic CAN Node.brd, Magic CAN Node.sch]
2014-12-22 Update component PARTNO attributes for BOM
    [Magic CAN Node.brd, Magic CAN Node.sch]
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2015-01-11 Switch to Jenn's MCAD
    [43045-0609.SLDPRT, 55959-2030.SLDPRT, ISO-1050.SLDPRT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]
2015-03-12 Update MCN top mechanical drawing to be more useful. Remove junk labels from brd.
    [Magic CAN Node.brd, Magic CAN Node.sch]
2015-03-23 Update CAN circuit to use SN65HVD1050 TX/RX.
    [Magic CAN Node.brd, Magic CAN Node.sch]
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2015-03-23 Update schematic title block and generate new PDFs.
    [Magic CAN Node.brd, Magic CAN Node.sch]
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2015-04-05 Update schematic and board for v2.1 (labels); route CAN-TX LED
    [Magic CAN Node.brd, Magic CAN Node.sch]
2015-04-05 Update PDFs, Gerbers, and BOM for v2.3
    [Magic CAN Node BOM.csv, Magic CAN Node.brd, Magic CAN Node.sch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]
2015-04-07 Connect VREFHI to +3V3 (issue #14).
    [Magic CAN Node.brd, Magic CAN Node.sch]
2015-04-07 Update BOM for v2.3
    [Magic CAN Node BOM.csv]
2015-04-07 Update CAM files for v2.3.
    [Bottom Layer.GBL, Drills.xln, Top Layer.GTL]
2015-06-04 Change LED resistors to reasonable values.
    [Magic CAN Node.brd, Magic CAN Node.sch]
2015-12-17 Add X4, blind-mate pin header for CAN connection
    [Magic CAN Node.brd, Magic CAN Node.sch]
2015-12-18 Add input protection to GP1 and GP0; begin placing input protection components
    [Magic CAN Node.brd, Magic CAN Node.sch]
2015-12-18 Route protection circuits for GP0 and GP1.
    [Magic CAN Node.brd]
2015-12-18 Assign part numbers; remove schematic CHANGE notes from v2.1.0
    [Magic CAN Node.brd, Magic CAN Node.sch]
2015-12-18 Update documentation. Consolidate some part numbers to reduce unique part counts.
    [Magic CAN Node BOM.csv, Magic CAN Node.brd, Magic CAN Node.sch]
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2015-12-21 Update Magic CAN Node with changes in Harwin.lbr
    [Magic CAN Node.brd, Magic CAN Node.sch]
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2015-12-28 Clear misc. ERC errors
    [Magic CAN Node.brd, Magic CAN Node.sch]
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
